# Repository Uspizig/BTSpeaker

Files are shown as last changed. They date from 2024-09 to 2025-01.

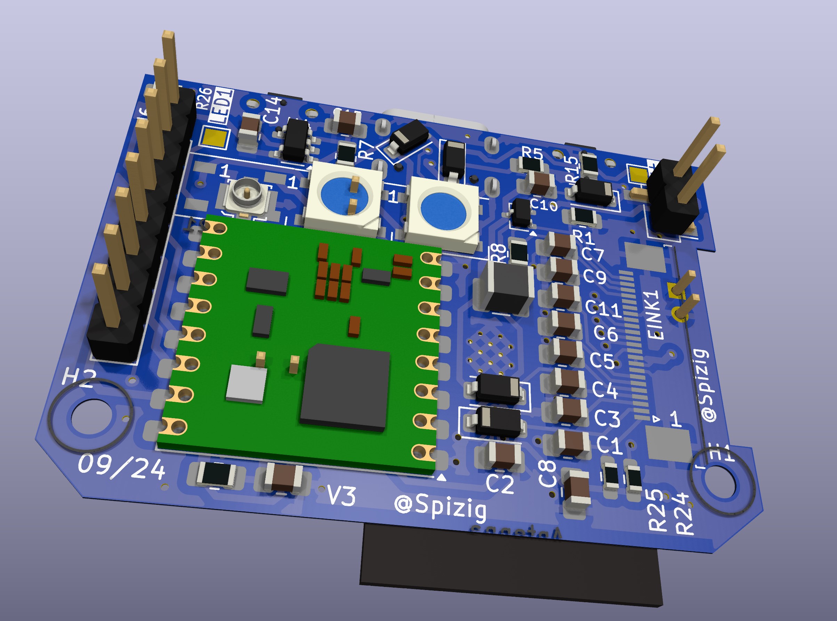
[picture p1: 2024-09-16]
Hardware/btspeakerV4/images/Screenshot 2024-09-01 205433.jpg

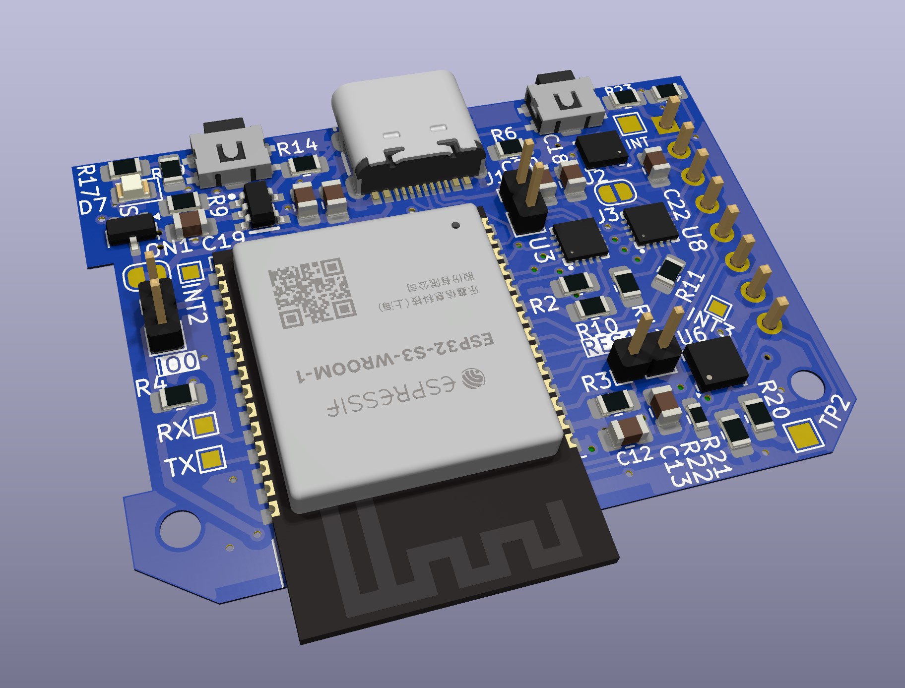
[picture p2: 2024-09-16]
Hardware/btspeakerV4/images/Screenshot 2024-09-01 211627.jpg

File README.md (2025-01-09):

# BTSpeaker: The retrofit Board for an cheap Aliexpress Speaker

<p align="center">

</p>

## Features:

1. **AudioAmplifier MAX98357**: Listen to your favourite Tunes with an Audio Amplifier

2. **I2C Connector for Sensor**: Connect your favourite I2C Sensor board with the embedded 2.54mm connector

3. **LoRa**: Long Range Communication like Meshtastikm, The Thingsnetwork or Helium

4. **Wireless Control**: Untehther your development process with the wireless capabilities. With WiFi, Lora and BLE, this tool allows remote control and data logging. Users can adjust settings and monitor data from a distance, offering a more flexible development experience.

5. **Open Source & Programmable**: As an open-source device, the Device offers unmatched versatility. It is fully programmable, allowing you to tailor its functionality to your specific applications. This customization extends to software and hardware, opening up endless possibilities for creative and efficient project development.

6. **Compact Design**: Designed for convenience, the LoRaCam Board compact and sleek form factor allows for seamless integration into existing setups. Its compatibility with USB PD power sources and inline integration capability minimizes the need for additional equipment or extensive redesign, making it a versatile and user-friendly addition to any development environment.

7. **Eink/Epaper-Display**: Monitor live the current status

<p align="center">

</p>

8. **LoRa**: Operate the Device in remote areas without Wifi in Standalone mode

9. **3 x RGB LED**: Status LED
## Specifications

<p align="center">

</p>

<p align="center">

</p>

### Key Features:
1. **Audio Player**: Play your favorite tunes from SD Card
2. **Web Radio**: Play your favourite tunes from the Web
3. **RGB LEDs** Illuminate your room with fany colors
4. **GYRO** Monitor movements, steps, pedometer

### Future Developments:

AI Detection of movememt and determine if the device shall sent the data via LoRa 

## Testing for Performance

At the heart of BTSpeaker's design is a commitment to reliability and performance. To ensure that SenseLoRaCam stands up to real-world demands, we subjected it to testing under use conditions.

## License

MIT License

Copyright (c) 2025 blue2monster

Permission is hereby granted, free of charge, to any person obtaining a copy
of this software and associated documentation files (the "Software"), to deal
in the Software without restriction, including without limitation the rights
to use, copy, modify, merge, publish, distribute, sublicense, and/or sell
copies of the Software, and to permit persons to whom the Software is
furnished to do so, subject to the following conditions:

The above copyright notice and this permission notice shall be included in all
copies or substantial portions of the Software.

THE SOFTWARE IS PROVIDED "AS IS", WITHOUT WARRANTY OF ANY KIND, EXPRESS OR
IMPLIED, INCLUDING BUT NOT LIMITED TO THE WARRANTIES OF MERCHANTABILITY,
FITNESS FOR A PARTICULAR PURPOSE AND NONINFRINGEMENT. IN NO EVENT SHALL THE
AUTHORS OR COPYRIGHT HOLDERS BE LIABLE FOR ANY CLAIM, DAMAGES OR OTHER
LIABILITY, WHETHER IN AN ACTION OF CONTRACT, TORT OR OTHERWISE, ARISING FROM,
OUT OF OR IN CONNECTION WITH THE SOFTWARE OR THE USE OR OTHER DEALINGS IN THE
SOFTWARE.

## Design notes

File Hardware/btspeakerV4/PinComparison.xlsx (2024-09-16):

ESP32-C6 | WROOM |  | ESP32-S3 | WROOM
Pin Number | Funktion | Besonderheiten | Pin Number |  | SmartKnob Function
1 | GND |  | 1 | GND
2 | 3V3 |  | 2 | 3V3
3 | EN |  | 3 | EN
4 | IO4 |  | 4 | IO4 | LORA DIO2 | HEADER
5 | IO5 |  | 5 | IO5 | LORA DIO5 | HEADER
6 | IO6 |  | 6 | IO6 | Header
7 | IO7 |  | 7 | IO7 | Header
8 | IO0 |  | 8 | IO15 | LORA RES | AUDIO SD2
9 | IO1 |  | 9 | IO16 | AUDIO SD
10 | IO8 | Strapping Pin | 10 | IO17 | AUDIO DIN
11 | IO10 |  | 11 | IO18 | AUDIO BCLK
12 | IO11 |  | 12 | IO8 | AUDIO LRC
13 | IO12 |  | 13 | IO19 | USB D-
14 | IO13 |  | 14 | IO20 | USB D+
 |  |  | 15 | IO3 | BUTTON 2
 |  |  | 16 | IO46 | x
 |  |  | 17 | IO9 | xxxx
 |  |  | 18 | IO10 | LORA CS
 |  |  | 19 | IO11 | LORA CLK
 |  |  | 20 | IO12 | LORA MOSI
 |  |  | 21 | IO13 | Button 1
 |  |  | 22 | IO14 | EPD RST
 |  |  | 23 | IO21 | EPD BUSY | J9 hinzu
 |  |  | 24 | IO47 | JP1
 |  |  | 25 | IO48 | x
 |  |  | 26 | IO45 | TP3
15 | IO9 | IO0 | 27 | IO0 | IO0
16 | IO18 | EPD_BU2 | 28 | IO35 | SPARE IO
17 | IO19 |  | 29 | IO36 | SPARE IO
18 | IO20 |  | 30 | IO37 | SPAREIO
19 | IO21 |  | 31 | IO38 | EPD_DC
20 | IO22 |  | 32 | IO39 | EPD CS
21 | IO23 |  | 33 | IO40 | EPD CLK
22 | NC |  | 34 | IO41 | EPD MOSI
23 | IO15 | JTAG SIGNAL | 35 | IO42 | LORA MISO | Fixed with J8
24 | RXD |  | 36 | RXD | RXD
25 | TXD |  | 37 | TXD | RXD
26 | IO3 | WS2812 | 38 | IO2 | Header
27 | IO2 | BLK | 39 | IO1 | Header
28 | GND |  | 40 | GND

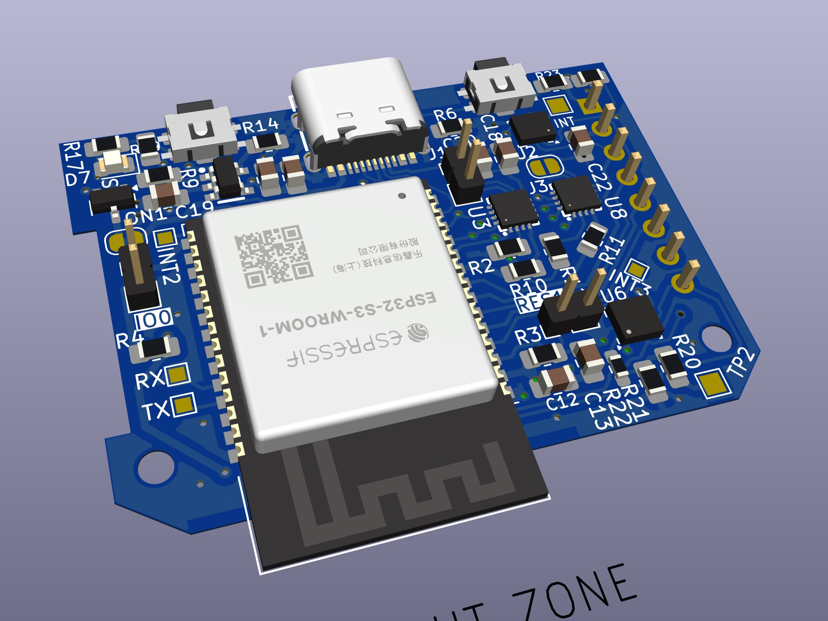
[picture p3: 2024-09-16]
Hardware/btspeakerV4/images/Screenshot 2024-09-01 211504.jpg

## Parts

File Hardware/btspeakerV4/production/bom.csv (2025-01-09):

Designator | Footprint | Quantity | Value | LCSC Part #
+5V, INT2 | TestPoint_Pad_1.5x1.5mm | 2 | TestPoint
AE1 | U.FL_Molex_MCRF_73412-0110_Vertical | 1 | Antenna_Shield
BAT | PinHeader_1x02_P2.54mm_Vertical_SMD_Pin1Left | 1 | PWR
C1, C11, C16, C2, C3, C4, C5, C6, C7, C9 | 0805 | 10 | 1uF
C10, C12, C14, C15 | 0805 | 4 | 4.7uF50V
C13, C21, C24, C25, C26 | 0603 | 5 | 100nF
C17, C18, C19, C20, C22, C23, C8 | 0805 | 7 | 100nF
D1, D2, D3 | D_SOD-123 | 3 | MBR0530
D4, D5, D6 | LED_WS2812B_PLCC4_5.0x5.0mm_P3.2mm | 3 | WS2812B
D7 | 0805 | 1 | LED
D8 | D_SOD-323 | 1 | MBR0530
EINK1 | TE_2-1734839-4_1x24-1MP_P0.5mm_Horizontal | 1 | FPCConn
H1, H2 | MountingHole_2.2mm_M2 | 2 | MountingHole
I3 | TestPoint_Pad_D1.0mm | 1 | TestPoint
INT1, RX, TX | TestPoint_Pad_1.0x1.0mm | 3 | TestPoint
IO0 | PinHeader_1x02_P1.27mm_Vertical | 1 | Conn_01x02_Pin
J1, RES | PinHeader_1x02_P2.00mm_Vertical | 2 | Conn_01x02_Pin
J2 | TF-SMD_XKTF-0803-0 | 1 | Micro_SD_Card_Det_US
J3 | SolderJumper-2_P1.3mm_Open_RoundedPad1.0x1.5mm | 1 | Conn_01x02_Pin
J5, J7 | PinHeader_1x03_P2.54mm_Vertical_SMD_Pin1Left | 2 | Conn_01x03_Pin
J6 | PinHeader_1x08_P2.54mm_Vertical | 1 | Conn_01x08_Pin
J9, ON | SolderJumper-2_P1.3mm_Bridged_RoundedPad1.0x1.5mm | 2 | Conn_01x02_Pin
JOG | JogWheel | 1 | jogdial
JP2 | SolderJumper-2_P1.3mm_Bridged_RoundedPad1.0x1.5mm | 1 | SolderJumper_2_Bridged
L1 | 1210 | 1 | 68uH1A
Q1 | SOT-323_SC-70 | 1 | Si1308
R1, R10, R13, R18 | 0805 | 4 | 10K
R11, R19 | 0805 | 2 | 300K
R12, R15, R17, R2 | 0805 | 4 | 100K
R14, R3, R9 | 0805 | 3 | 1K
R16, R20, R21 | 0603 | 3 | 100K
R23 | 0603 | 1 | 22
R24, R25, R4 | 0603 | 3 | 10K
R26 | 0603 | 1 | 0R
R27 | 0603 | 1 | N.C.
R5, R6 | 0805 | 2 | 5k11
R7 | 0805 | 1 | 0R
R8 | 0805 | 1 | 3R
SI2 | SOT-23 | 1 | SI2301CDS
SW1, SW2 | SW_SPST_CK_KMS2xxGP | 2 | SW_Push
U1 | ESP32-S3-WROOM-1 | 1 | ESP32-S3-WROOM-1-Espressif
U10 | LGA-12_2x2mm_P0.5mm | 1 | LIS3MDL
U11 | GC9A01_IPS_display_reversed | 1 | GC9A01_IPS_display
U12 | LGA-16_3x3mm_P0.5mm | 1 | MMC5883MA
U13, U9 | Bosch_LGA-8_2.5x2.5mm_P0.65mm_ClockwisePinNumbering | 2 | BME280
U2 | LGA-14_3x2.5mm_P0.5mm_LayoutBorder3x4y | 1 | LSM6DS3
U3, U8 | TQFN-16_L3.0-W3.0-P0.50-BL-EP1.5 | 2 | ~
U4 | SOT-23-5 | 1 | RT9013
U5 | HOPERF_RFM9XW_SMD | 1 | RFM95W-868S2
U6 | ZMOD4410AI1V | 1 | 4410AI1V
U7 | SOT-23-5_L3.0-W1.7-P0.95-LS2.8-BR | 1 | TP4065
USB | USB-C_SMD-TYPE-C-31-M-12 | 1 | KoreanHropartsElecTYPE-C-31-M-12

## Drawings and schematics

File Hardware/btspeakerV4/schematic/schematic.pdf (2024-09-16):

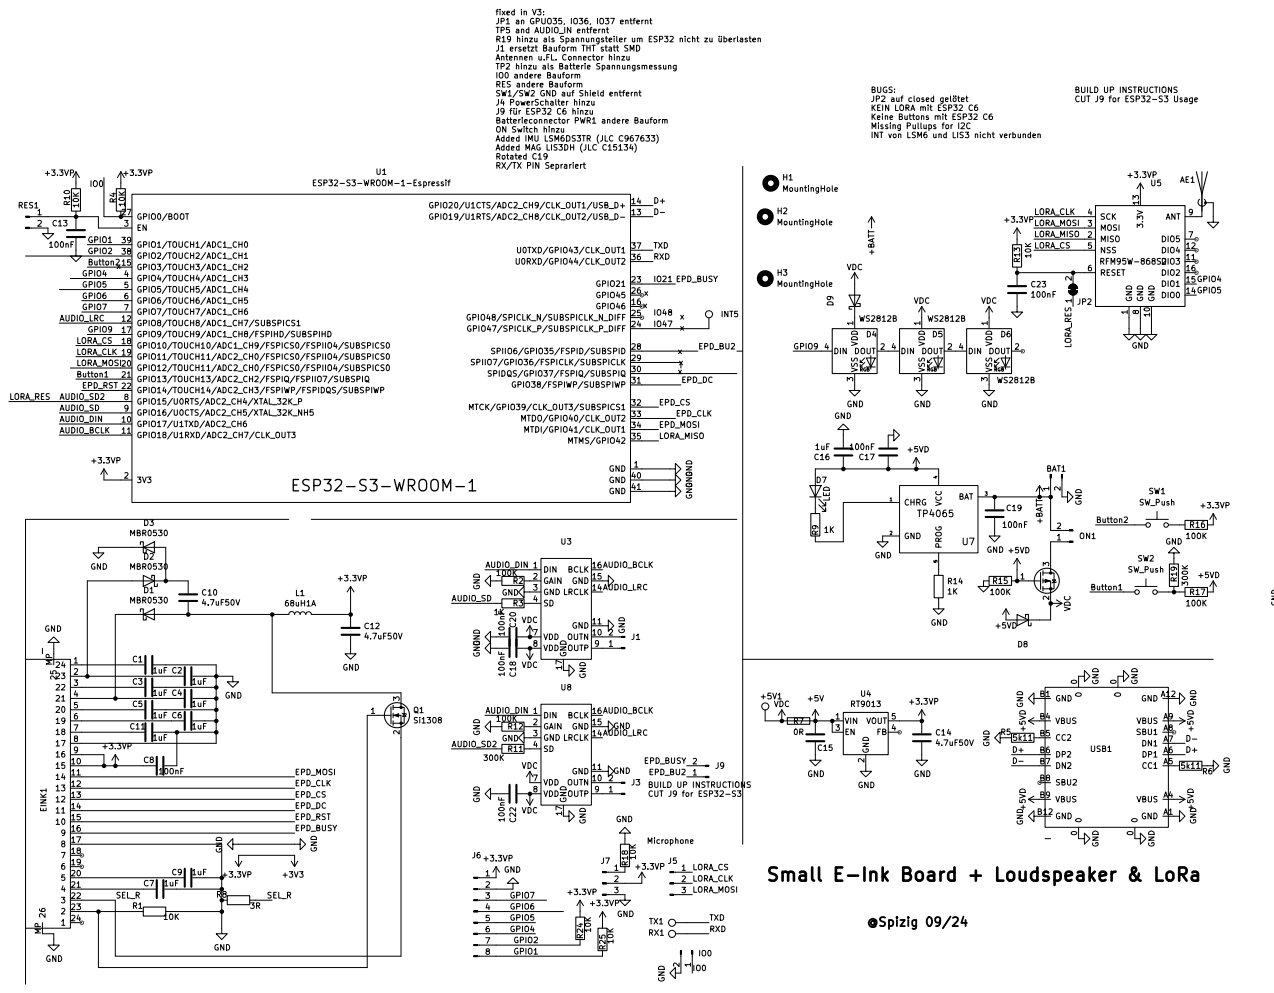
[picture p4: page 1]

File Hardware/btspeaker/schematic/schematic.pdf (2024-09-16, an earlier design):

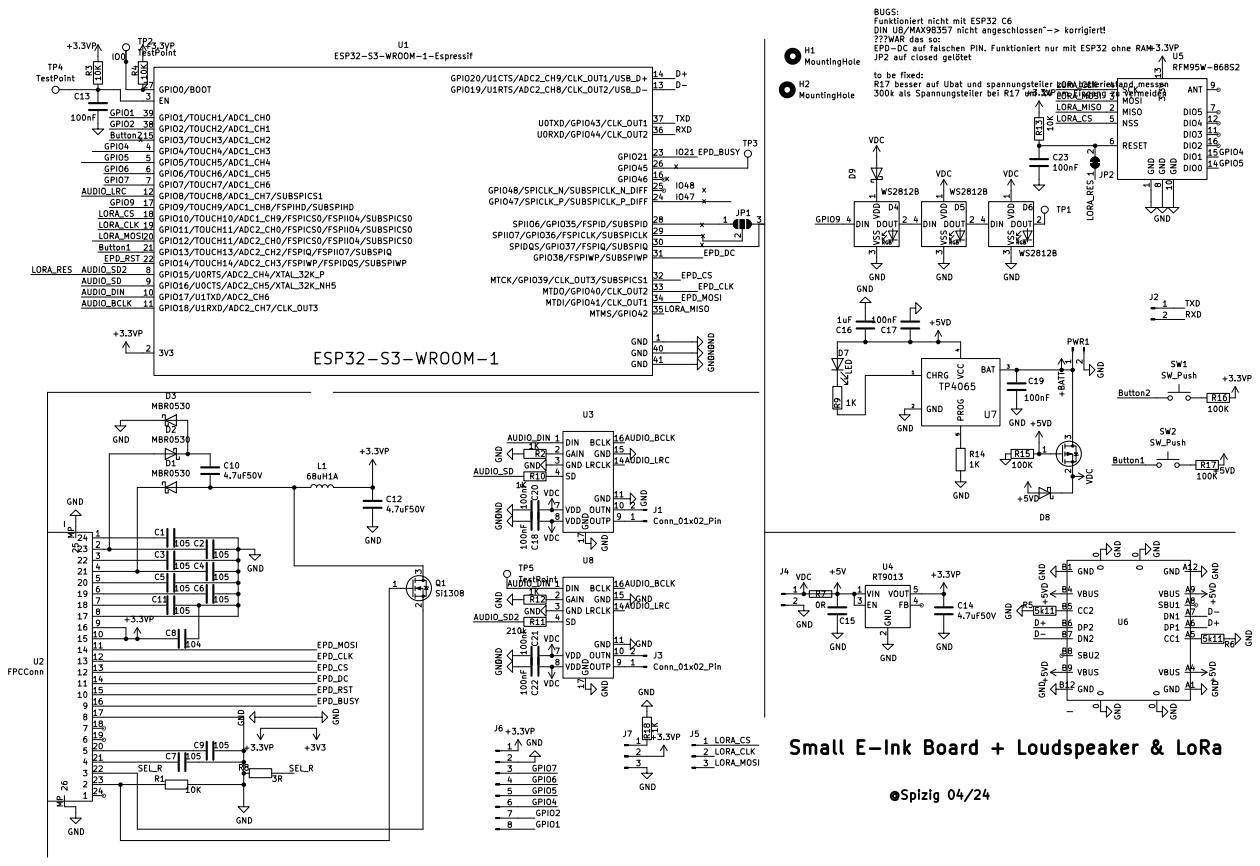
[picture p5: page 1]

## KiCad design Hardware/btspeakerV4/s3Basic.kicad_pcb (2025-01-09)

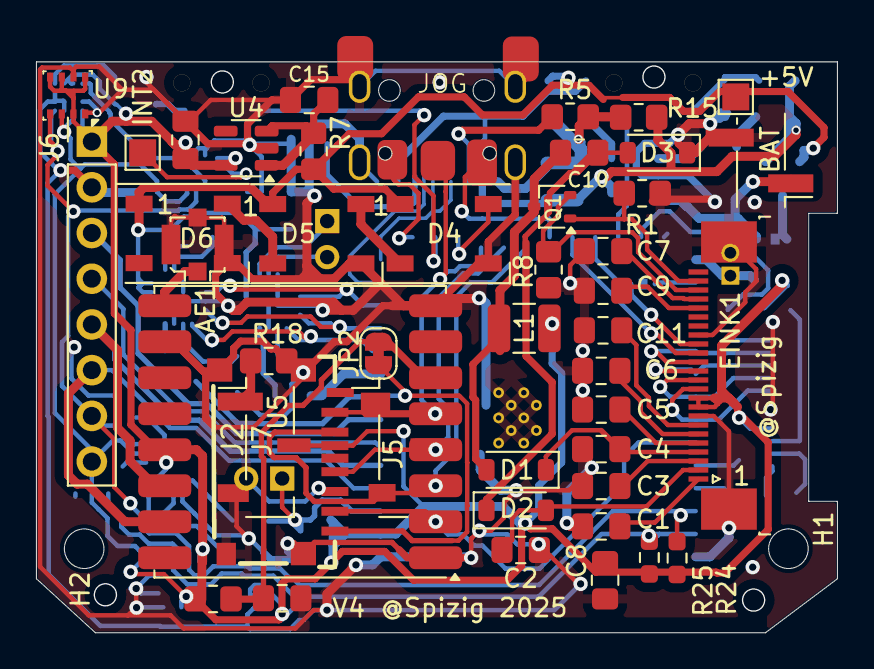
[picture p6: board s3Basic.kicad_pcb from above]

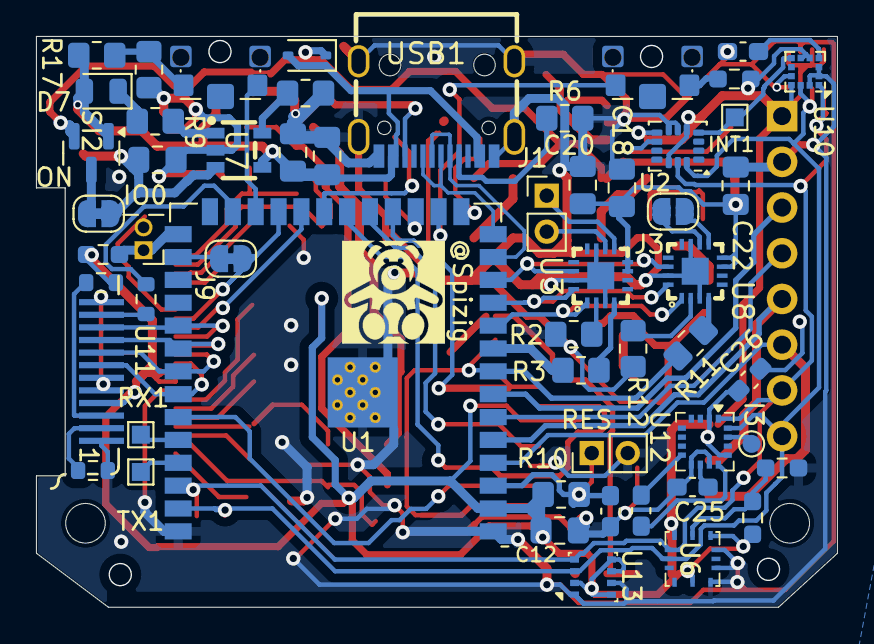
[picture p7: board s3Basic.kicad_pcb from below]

Board: 2 copper layers, 44.5 x 31.7 mm, 103 parts (56 on the bottom side), 85 nets.

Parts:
+5V: TestPoint; TestPoint_Pad_1.5x1.5mm
AE1: Antenna_Shield; U.FL_Molex_MCRF_73412-0110_Vertical
BAT: PWR; PinHeader_1x02_P2.54mm_Vertical_SMD_Pin1Left
C1, C2, C3, C4, C5, C6, C7, C9, C11, C16: 1uF; C_0805_2012Metric_Pad1.18x1.45mm_HandSolder
C8, C17, C18, C19, C20, C22, C23: 100nF; C_0805_2012Metric_Pad1.18x1.45mm_HandSolder
C10, C12, C14, C15: 4.7uF50V; C_0805_2012Metric_Pad1.18x1.45mm_HandSolder
C13, C21, C24, C25, C26: 100nF; C_0603_1608Metric_Pad1.08x0.95mm_HandSolder
D1, D2, D3: MBR0530; D_SOD-123
D4, D5, D6: WS2812B; LED_WS2812B_PLCC4_5.0x5.0mm_P3.2mm
D7: LED; LED_0805_2012Metric
D8: MBR0530; D_SOD-323
EINK1: FPCConn; TE_2-1734839-4_1x24-1MP_P0.5mm_Horizontal
H1, H2: MountingHole; MountingHole_2.2mm_M2
H3: MountingHole; baerklein
I3: TestPoint; TestPoint_Pad_D1.0mm
INT1: TestPoint; TestPoint_Pad_1.0x1.0mm
INT2: TestPoint; TestPoint_Pad_1.5x1.5mm
IO0: Conn_01x02_Pin; PinHeader_1x02_P1.27mm_Vertical
J1: Conn_01x02_Pin; PinHeader_1x02_P2.00mm_Vertical
J2: Micro_SD_Card_Det_US; TF-SMD_XKTF-0803-0
J3: Conn_01x02_Pin; SolderJumper-2_P1.3mm_Open_RoundedPad1.0x1.5mm
J5, J7: Conn_01x03_Pin; PinHeader_1x03_P2.54mm_Vertical_SMD_Pin1Left
J6: Conn_01x08_Pin; PinHeader_1x08_P2.54mm_Vertical
J9: Conn_01x02_Pin; SolderJumper-2_P1.3mm_Bridged_RoundedPad1.0x1.5mm
JOG: jogdial; JogWheel
JP2: SolderJumper_2_Bridged; SolderJumper-2_P1.3mm_Bridged_RoundedPad1.0x1.5mm
L1: 68uH1A; L_1210_3225Metric
ON: Conn_01x02_Pin; SolderJumper-2_P1.3mm_Bridged_RoundedPad1.0x1.5mm
Q1: Si1308; SOT-323_SC-70
R1, R10, R13, R18: 10K; R_0805_2012Metric_Pad1.20x1.40mm_HandSolder
R2, R12, R15, R17: 100K; R_0805_2012Metric_Pad1.20x1.40mm_HandSolder
R3, R9, R14: 1K; R_0805_2012Metric_Pad1.20x1.40mm_HandSolder
R4, R24, R25: 10K; R_0603_1608Metric_Pad0.98x0.95mm_HandSolder
R5, R6: 5k11; R_0805_2012Metric_Pad1.20x1.40mm_HandSolder
R7: 0R; R_0805_2012Metric_Pad1.20x1.40mm_HandSolder
R8: 3R; R_0805_2012Metric_Pad1.20x1.40mm_HandSolder
R11, R19: 300K; R_0805_2012Metric_Pad1.20x1.40mm_HandSolder
R16, R20, R21: 100K; R_0603_1608Metric_Pad0.98x0.95mm_HandSolder
R23: 22; R_0603_1608Metric
R26: 0R; R_0603_1608Metric
R27: N.C.; R_0603_1608Metric
RES: Conn_01x02_Pin; PinHeader_1x02_P2.00mm_Vertical
RX1: TestPoint; TestPoint_Pad_1.0x1.0mm
SI2: SI2301CDS; SOT-23
SW1, SW2: SW_Push; SW_SPST_CK_KMS2xxGP
TX1: TestPoint; TestPoint_Pad_1.0x1.0mm
U1: ESP32-S3-WROOM-1-Espressif; ESP32-S3-WROOM-1
U2: LSM6DS3; LGA-14_3x2.5mm_P0.5mm_LayoutBorder3x4y
U3, U8: TQFN-16_L3.0-W3.0-P0.50-BL-EP1.5
U4: RT9013; SOT-23-5
U5: RFM95W-868S2; HOPERF_RFM9XW_SMD
U6: 4410AI1V; ZMOD4410AI1V
U7: TP4065; SOT-23-5_L3.0-W1.7-P0.95-LS2.8-BR
U9, U13: BME280; Bosch_LGA-8_2.5x2.5mm_P0.65mm_ClockwisePinNumbering
U10: LIS3MDL; LGA-12_2x2mm_P0.5mm
U11: GC9A01_IPS_display; GC9A01_IPS_display_reversed
U12: MMC5883MA; LGA-16_3x3mm_P0.5mm
USB1: KoreanHropartsElecTYPE-C-31-M-12; USB-C_SMD-TYPE-C-31-M-12

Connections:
+3.3VP: C8.2, C12.2, C14.2, C26.1, EINK1.9 (16), EINK1.10 (15), J2.4 (VDD), J6.1, J7.2, L1.2, R4.2, R10.2, R13.2, R16.1, R21.1, R23.2, R24.1, R25.1, U1.2 (3V3), U2.5 (VDDIO), U2.8 (VDD), U2.12 (CS), U4.5 (VOUT), U5.13 (3.3V), U6.5 (VDD), U6.10 (VDDH), U6.12 (VDDIO), U9.2 (CSB), U9.5 (SDO), U9.6 (VDDIO), U9.8 (VDD), U10.5 (Vdd), U10.6 (Vdd_IO), U10.10 (~CS), U11.4 (VDD), U12.2 (VDD), U12.13 (VDDIO), U13.2 (CSB), U13.5 (SDO), U13.6 (VDDIO), U13.8 (VDD)
+5V: C15.2, R7.1, U4.1 (VIN), U4.3 (EN)
+5VD: C16.1, C17.1, D7.2 (A), D8.2 (A), R15.1, R17.1, SI2.1 (G), U7.4 (VCC), USB1.A4 (VBUS), USB1.A9 (VBUS), USB1.B4 (VBUS), USB1.B9 (VBUS)
+BATT: BAT.1, C19.2, ON.2, U7.3 (BAT)
/AUDIO_BCLK: U1.11 (GPIO18/U1RXD/ADC2_CH7/CLK_OUT3), U3.16 (BCLK), U8.16 (BCLK)
/AUDIO_DIN: U1.10 (GPIO17/U1TXD/ADC2_CH6), U3.1 (DIN), U8.1 (DIN)
/AUDIO_LRC: U1.12 (GPIO8/TOUCH8/ADC1_CH7/SUBSPICS1), U3.14 (LRCLK), U8.14 (LRCLK)
/AUDIO_SD: R3.1, U1.9 (GPIO16/U0CTS/ADC2_CH5/XTAL_32K_NH5)
/AUDIO_SD2: J2.8 (DAT1), JP2.1 (A), R11.1, U1.8 (GPIO15/U0RTS/ADC2_CH4/XTAL_32K_P)
/Button1: SW2.1, U1.24 (GPIO47/SPICLK_P/SUBSPICLK_P_DIFF)
/Button2: SW1.2, U1.16 (GPIO46)
/D+: U1.14 (GPIO20/U1CTS/ADC2_CH9/CLK_OUT1/USB_D+), USB1.A6 (DP1), USB1.B6 (DP2)
/D-: U1.13 (GPIO19/U1RTS/ADC2_CH8/CLK_OUT2/USB_D-), USB1.A7 (DN1), USB1.B7 (DN2)
/DISP_RES: R26.2, U1.25 (GPIO48/SPICLK_N/SUBSPICLK_N_DIFF)
/EPD_BU2: J9.1, U1.28 (SPIIO6/GPIO35/FSPID/SUBSPID)
/EPD_BUSY: EINK1.16 (9), J9.2, U1.23 (GPIO21)
/EPD_CLK: EINK1.12 (13), U1.33 (MTDO/GPIO40/CLK_OUT2), U11.8 (~CS)
/EPD_CS: EINK1.13 (12), U1.32 (MTCK/GPIO39/CLK_OUT3/SUBSPICS1), U11.9 (SCK)
/EPD_DC: EINK1.14 (11), U1.31 (GPIO38/FSPIWP/SUBSPIWP), U11.10 (SDI)
/EPD_MOSI: EINK1.11 (14), U1.34 (MTDI/GPIO41/CLK_OUT1), U11.7 (D/C)
/EPD_RST: EINK1.15 (10), U1.22 (GPIO14/TOUCH14/ADC2_CH3/FSPIWP/FSPIDQS/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)
/GPIO1: J6.8, R25.2, U1.39 (GPIO1/TOUCH1/ADC1_CH0), U2.14 (SDA), U6.2 (SDA), U9.3 (SDI), U10.11 (SDA/SDI/SDO), U12.16 (SDA), U13.3 (SDI)
/GPIO2: J6.7, R24.2, U1.38 (GPIO2/TOUCH2/ADC1_CH1), U2.13 (SCL), U6.1 (SCL), U9.4 (SCK), U10.1 (SCL/SPC), U12.1 (SCL), U13.4 (SCK)
/GPIO4: J6.6, U1.4 (GPIO4/TOUCH4/ADC1_CH3), U5.15 (DIO1)
/GPIO5: J6.5, U1.5 (GPIO5/TOUCH5/ADC1_CH4), U5.14 (DIO0)
/GPIO6: J6.4, U1.6 (GPIO6/TOUCH6/ADC1_CH5)
/GPIO7: J6.3, U1.7 (GPIO7/TOUCH7/ADC1_CH6)
/GPIO9: D4.4 (DIN), U1.17 (GPIO9/TOUCH9/ADC1_CH8/FSPIHD/SUBSPIHD)
/INT1: INT1.1, U2.4 (INT1), U10.7 (INT)
/IO0: IO0.1, R4.1, U1.27 (GPIO0/BOOT)
/LORA_CLK: J2.5 (CLK), J5.2, U1.19 (GPIO11/TOUCH11/ADC2_CH0/FSPICS0/FSPIIO4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), U5.4 (SCK)
/LORA_CS: J2.2 (DAT3/CD), J5.1, JOG.2, U1.18 (GPIO10/TOUCH10/ADC1_CH9/FSPICS0/FSPIIO4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), U5.5 (NSS)
/LORA_MISO: J2.7 (DAT0), U1.35 (MTMS/GPIO42), U5.2 (MISO)
/LORA_MOSI: J2.3 (CMD), J5.3, U1.20 (GPIO12/TOUCH11/ADC2_CH0/FSPICS0/FSPIIO4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), U5.3 (MOSI)
/ROT_A: JOG.1, U1.15 (GPIO3/TOUCH3/ADC1_CH2)
/ROT_B: JOG.3, U1.21 (GPIO13/TOUCH13/ADC2_CH2/FSPIQ/FSPIIO7/S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)
/RXD: RX1.1, U1.36 (U0RXD/GPIO44/CLK_OUT2)
/SEL_R: EINK1.22 (3), Q1.2 (S), R8.2
/TXD: TX1.1, U1.37 (U0TXD/GPIO43/CLK_OUT1)
GND: AE1.2 (Shield), BAT.2, C1.1, C2.1, C3.1, C4.1, C5.1, C6.1, C7.1, C8.1, C9.1, C11.1, C12.1, C13.1, C14.1, C15.1, C16.2, C17.2, C18.2, C19.1, C20.2, C21.1, C22.2, C23.1, C25.1, C26.2, D3.1 (K), D4.3 (VSS), D5.3 (VSS), D6.3 (VSS), EINK1.8 (17), EINK1.17 (8), EINK1.MP (26), IO0.2, J2.6 (VSS), J2.10 (SHELL), J2.11 (SHELL), J2.12 (SHELL), J2.13 (SHELL), J6.2, J7.3, JOG.4, R1.2, R2.1, R5.1, R6.1, R8.1, R12.1, R14.2, R15.2, R18.1, R19.1, R20.1, R27.1, RES.2, U1.1 (GND), U1.40 (GND), U1.41 (GND), U2.6 (GND), U2.7 (GND), U3.3 (GND), U3.11 (GND), U3.15 (GND), U3.17 (GND), U4.2 (GND), U5.1 (GND), U5.8 (GND), U5.10 (GND), U6.6 (VSS), U6.7 (VSS), U6.9 (VSS), U7.2 (GND), U8.3 (GND), U8.11 (GND), U8.15 (GND), U8.17 (GND), U9.1 (GND), U9.7 (GND), U10.2 (GND), U10.3 (GND), U10.9 (SDO/SA1), U10.12 (GND), U11.1 (GND), U11.5 (GND), U11.6 (GND), U11.12 (GND), U12.9 (GND), U12.11 (GND), U13.1 (GND), U13.7 (GND), USB1.0, USB1.A1 (GND), USB1.A12 (GND), USB1.B1 (GND), USB1.B12 (GND)
unnamed: AE1.1 (A), U5.9 (ANT)
unnamed: C10.1, D1.2 (A), L1.1, Q1.3 (D)
unnamed: C4.2, D1.1 (K), EINK1.4 (21)
unnamed: C2.2, D2.2 (A), EINK1.2 (23)
unnamed: C10.2, D2.1 (K), D3.2 (A)
unnamed: D4.2 (DOUT), D5.4 (DIN)
unnamed: D5.2 (DOUT), D6.4 (DIN)
unnamed: D7.1 (K), R9.1
unnamed: EINK1.23 (2), Q1.1 (G), R1.1
unnamed: C7.2, EINK1.21 (4)
unnamed: C9.2, EINK1.20 (5)
unnamed: C11.2, EINK1.7 (18)
unnamed: C6.2, EINK1.6 (19)
unnamed: C5.2, EINK1.5 (20)
unnamed: C3.2, EINK1.3 (22)
unnamed: C1.2, EINK1.1 (24)
unnamed: J1.1, U3.9 (OUTP)
unnamed: J1.2, U3.10 (OUTN)
unnamed: J3.1, U8.9 (OUTP)
unnamed: J3.2, U8.10 (OUTN)
unnamed: J7.1, R18.2
unnamed: C23.2, JP2.2 (B), R13.1, U5.6 (RESET)
unnamed: ON.1, SI2.3 (D)
unnamed: R16.2, SW1.1
unnamed: R17.2, R19.2, SW2.2
unnamed: C13.2, R10.1, RES.1, U1.3 (EN)
unnamed: INT2.1, U2.9 (INT2)
unnamed: R2.2, U3.2 (GAIN)
unnamed: R3.2, U3.4 (SD)
unnamed: R20.2, R21.2, U6.11 (RES_N)
unnamed: R9.2, U7.1 (CHRG)
unnamed: R14.1, U7.5 (PROG)
unnamed: R12.2, U8.2 (GAIN)
unnamed: R11.2, U8.4 (SD)
unnamed: C21.2, U10.4 (C1)
unnamed: R23.1, U11.3 (LEDA)
unnamed: R27.2, U11.2 (LEDK)
unnamed: R26.1, U11.11 (~RESET)
unnamed: C24.1, U12.8 (C1)
unnamed: C24.2, U12.12 (C2)
unnamed: C25.2, U12.10 (CAP)
unnamed: I3.1, U12.15 (INT)
unnamed: R6.2, USB1.A5 (CC1)
unnamed: R5.2, USB1.B5 (CC2)
VDC: +5V.1, C18.1, C20.1, C22.1, D4.1 (VDD), D5.1 (VDD), D6.1 (VDD), D8.1 (K), R7.2, SI2.2 (S), U3.7 (VDD), U3.8 (VDD), U8.7 (VDD), U8.8 (VDD)
